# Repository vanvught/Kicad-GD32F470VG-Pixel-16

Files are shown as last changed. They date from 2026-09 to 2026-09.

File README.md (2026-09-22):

# Kicad GD32F470VG Pixel 16-ports x 4 Universes

Firmware [https://github.com/vanvught/GD32F470VG-Pixel-16-Ports](https://github.com/vanvught/GD32F470VG-Pixel-16-Ports)

More information [https://www.gd32-dmx.org/pixel.html](https://www.gd32-dmx.org/pixel.html)

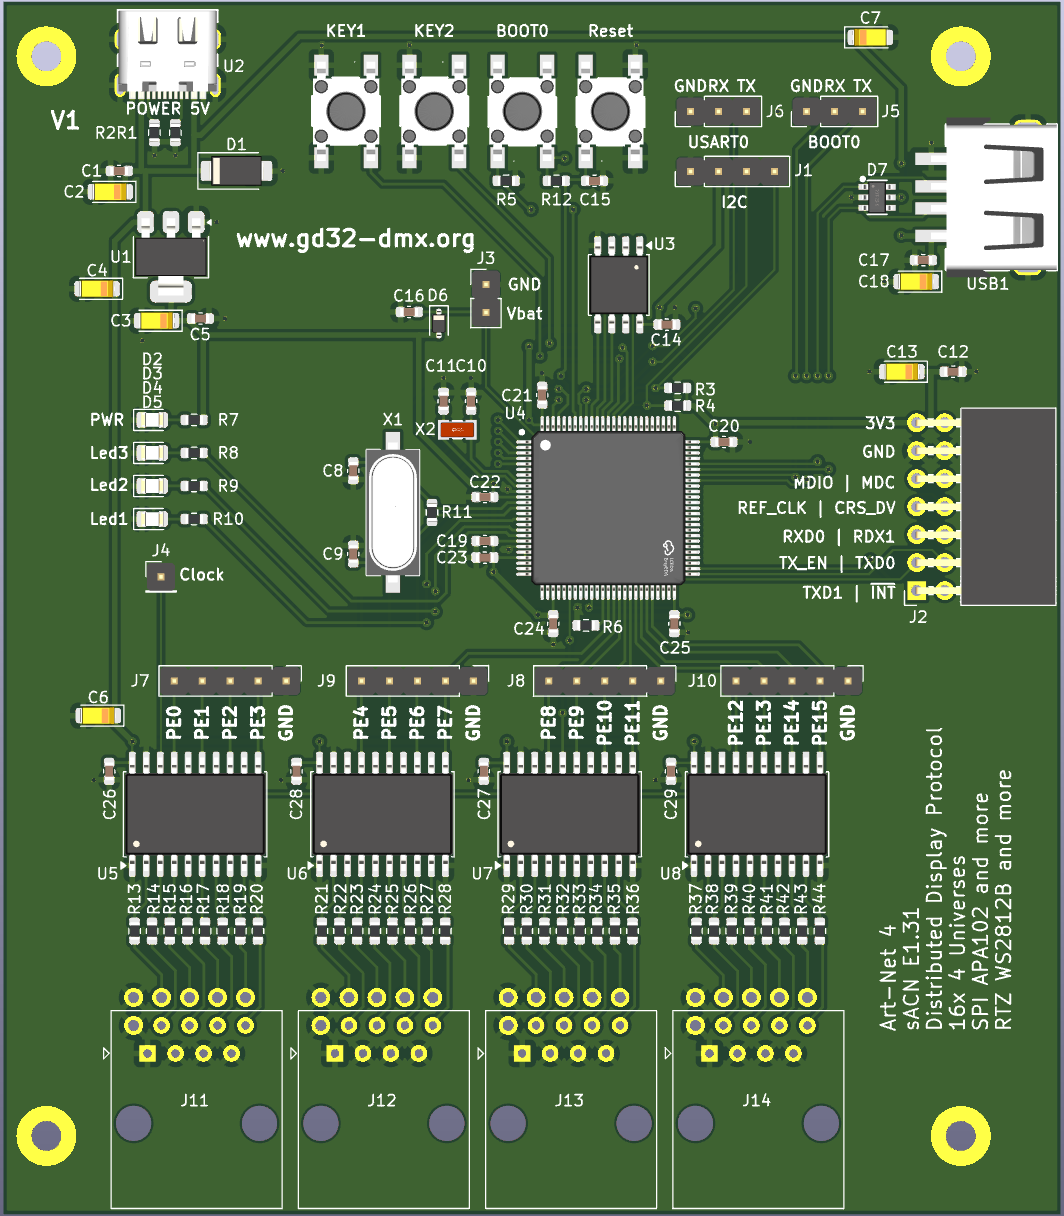
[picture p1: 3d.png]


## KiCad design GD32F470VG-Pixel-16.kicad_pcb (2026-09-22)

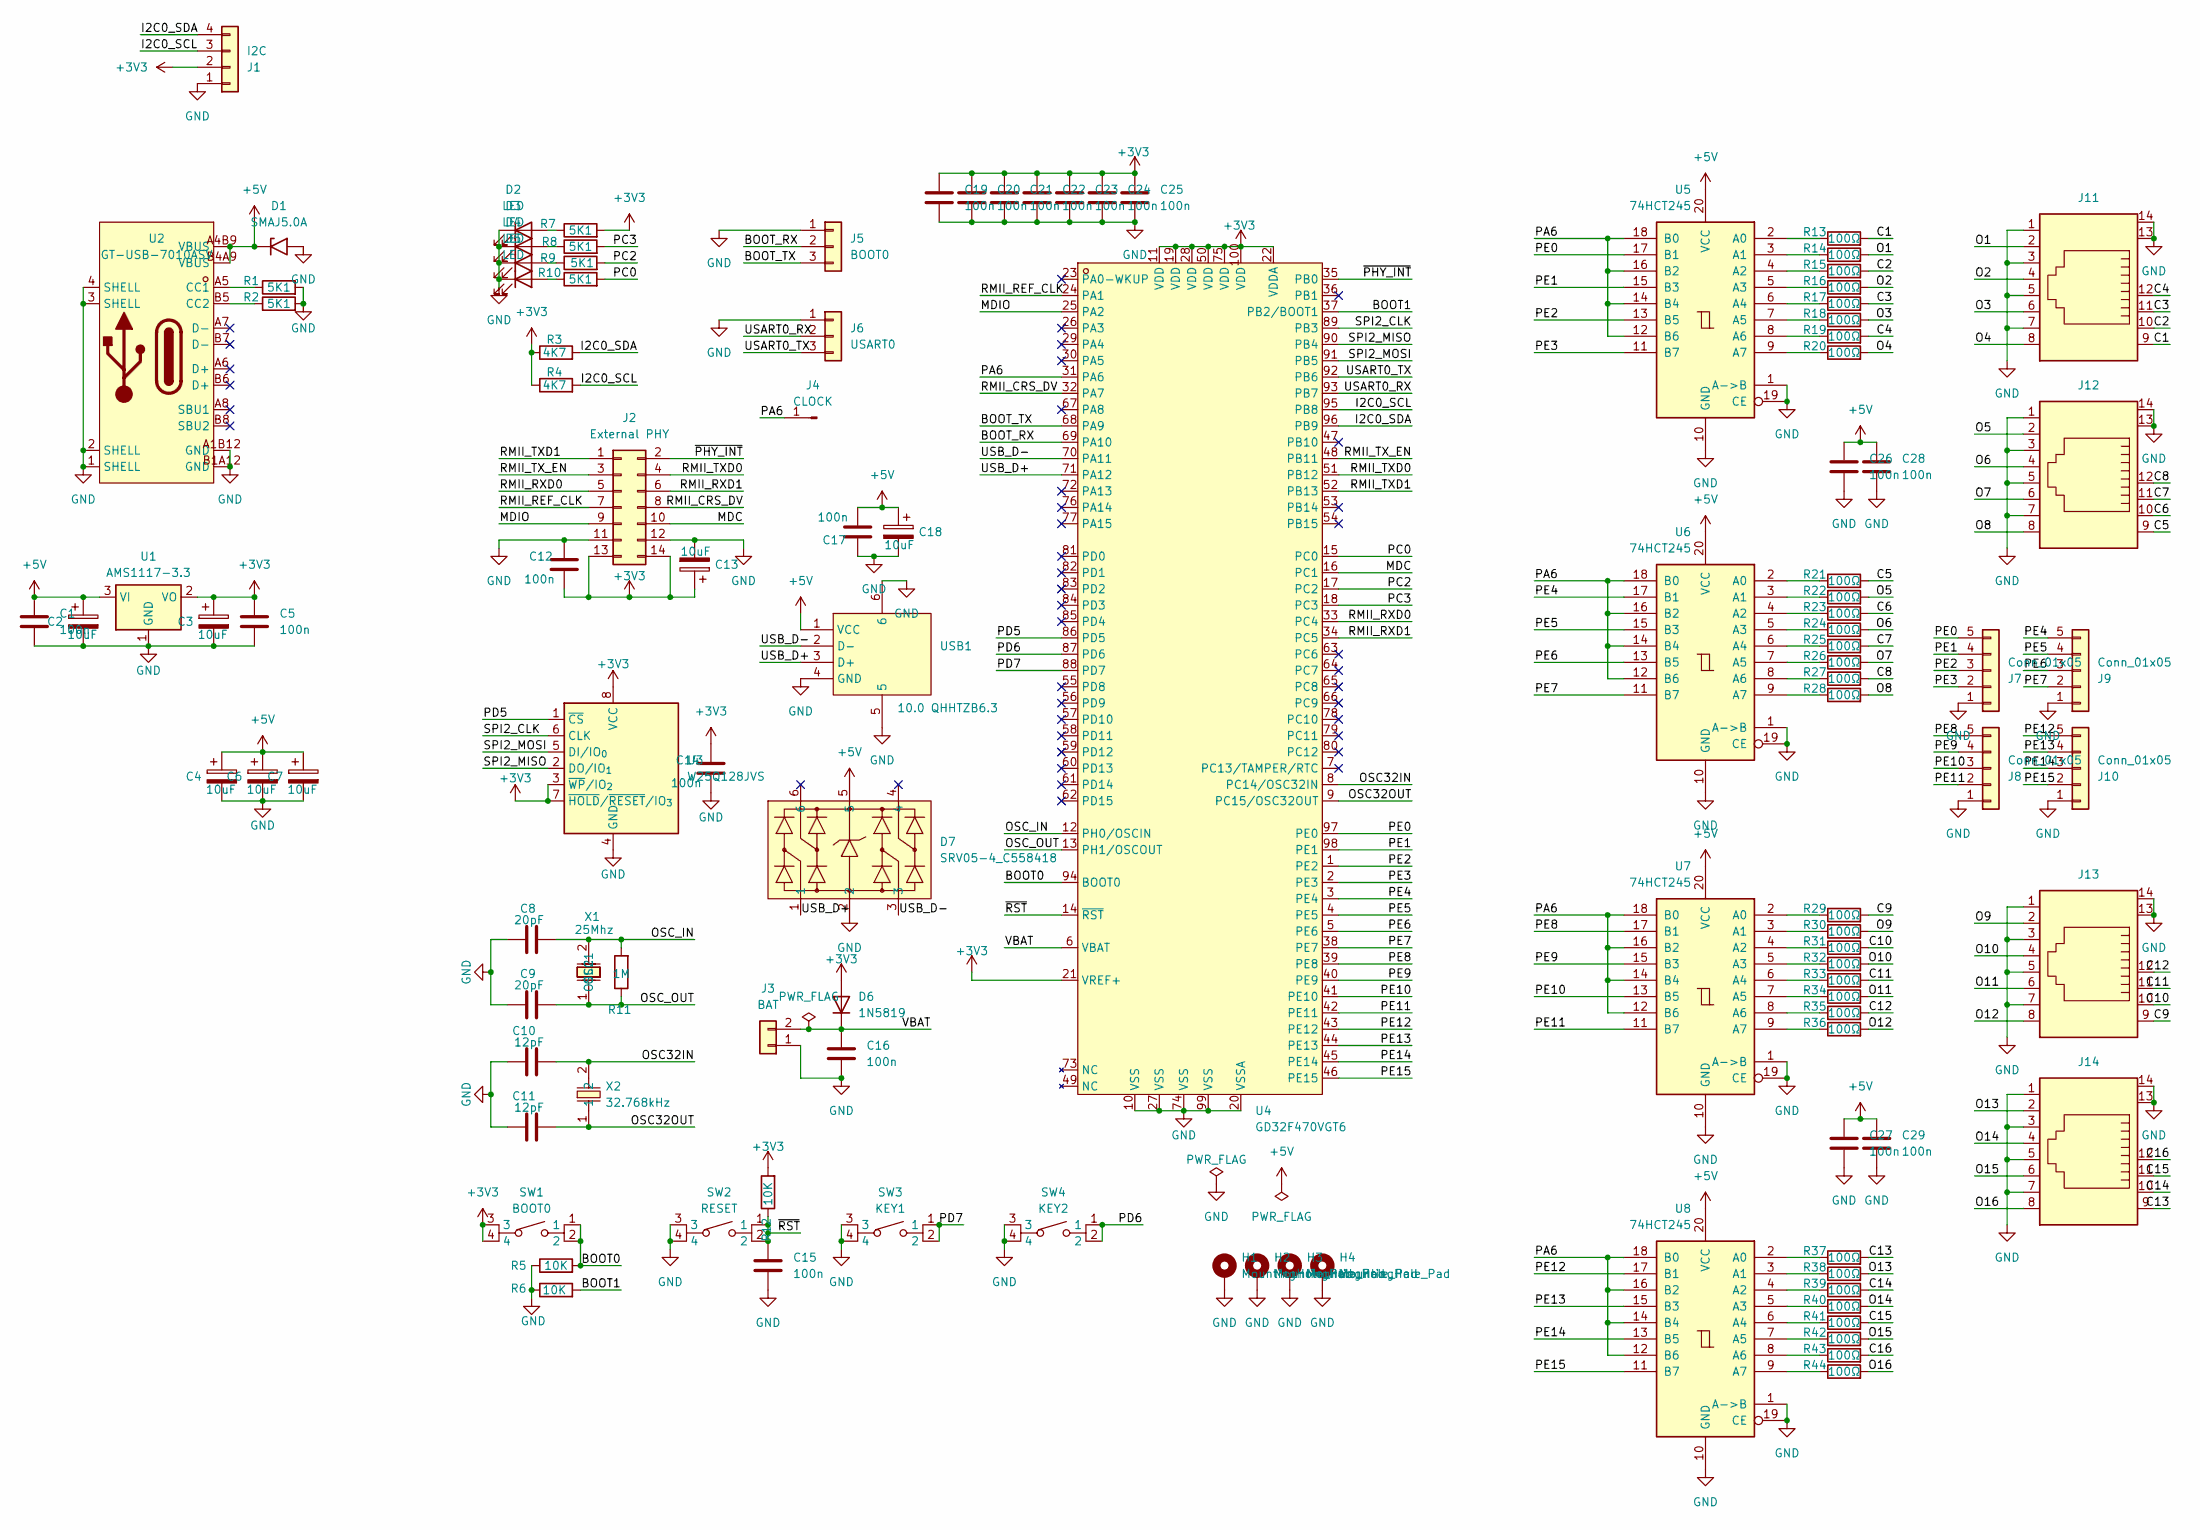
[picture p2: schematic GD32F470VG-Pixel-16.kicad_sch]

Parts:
C1, C5, C12, C14, C15, C16, C17, C19, C20, C21, C22, C23, C24, C25, C26, C27, C28, C29: 100n; C_0603_1608Metric; LCSC Part C14663
C2, C3, C4, C6, C7, C13, C18: 10uF; CP_EIA-3216-18_Kemet-A; LCSC Part C7171
C8, C9: 20pF; C_0603_1608Metric; LCSC Part C1648
C10, C11: 12pF; C_0603_1608Metric; LCSC Part C38523
D1: SMAJ5.0A; D_SMA; LCSC Part C113952
D2, D3, D4, D5: LED; LED_0805_2012Metric; LCSC Part C2297
D6: 1N5819; D_SOD-323; LCSC Part C48997863
D7: SRV05-4_C558418; SOT-23-6_L2.9-W1.6-P0.95-LS2.8-BL; MPN SRV05-4; LCSC Part C558418
H1, H2, H3, H4: MountingHole_Pad; MountingHole_2.7mm_M2.5_Pad
J1: I2C; PinHeader_1x04_P2.54mm_Vertical
J2: External PHY; PinSocket_2x07_P2.54mm_Horizontal
J3: BAT; PinHeader_1x02_P2.54mm_Vertical
J4: CLOCK; PinHeader_1x01_P2.54mm_Vertical
J5: BOOT0; PinHeader_1x03_P2.54mm_Vertical
J6: USART0; PinHeader_1x03_P2.54mm_Vertical
J7, J8, J9, J10: Conn_01x05; PinHeader_1x05_P2.54mm_Vertical
J11, J12, J13, J14: RJ45-with-additional-row
R1, R2, R7, R8, R9, R10: 5K1; R_0603_1608Metric; LCSC Part C23186
R3, R4: 4K7; R_0603_1608Metric; LCSC Part C23162
R5, R6, R12: 10K; R_0603_1608Metric; LCSC Part C25804
R11: 1M; R_0603_1608Metric; LCSC Part C22935
R13, R14, R15, R16, R17, R18, R19, R20, R21, R22, R23, R24, R25, R26, R27, R28, R29, R30, R31, R32, R33, R34, R35, R36, R37, R38, R39, R40, R41, R42, R43, R44: 100Ω; R_0603_1608Metric; LCSC Part C22775
SW1: BOOT0; KEY-SMD_4P-L6.0-W6.0-P4.50-LS9.0; MPN PTS645SM43SMTR92LFS; LCSC Part C221880
SW2: RESET; KEY-SMD_4P-L6.0-W6.0-P4.50-LS9.0; MPN PTS645SM43SMTR92LFS; LCSC Part C221880
SW3: KEY1; KEY-SMD_4P-L6.0-W6.0-P4.50-LS9.0; MPN PTS645SM43SMTR92LFS; LCSC Part C221880
SW4: KEY2; KEY-SMD_4P-L6.0-W6.0-P4.50-LS9.0; MPN PTS645SM43SMTR92LFS; LCSC Part C221880
U1: AMS1117-3.3; SOT-223-3_TabPin2
U2: GT-USB-7010ASV; USB-C-SMD_G-SWITCH_GT-USB-7010ASV; MPN GT-USB-7010ASV; LCSC Part C2988369
U3: W25Q128JVS; SOIC-8_5.3x5.3mm_P1.27mm; LCSC Part C97521
U4: GD32F470VGT6; LQFP-100_L14.0-W14.0-P0.50-LS16.0-BL; MPN GD32F470VGT6; LCSC Part C3029773
U5, U6, U7, U8: 74HCT245; SOIC-20W_7.5x12.8mm_P1.27mm; LCSC Part C5979
USB1: 10.0 QHHTZB6.3; USB-A-TH_10.0QHHTZB6.3; MPN 10.0 QHHTZB6.3; LCSC Part C668591
X1: 25Mhz; HC-49S_L11.4-W4.8; MPN X49SM25MSD2SC; LCSC Part C14872
X2: 32.768kHz; FC-135R_L3.2-W1.5; MPN Q13FC13500004; LCSC Part C32346

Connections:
+3V3: C3.1, C5.1, C12.2, C13.1, C14.1, C19.1, C20.1, C21.1, C22.1, C23.1, C24.1, C25.1, D6.2 (A), J1.2, J2.13, J2.14, R3.1, R4.1, R7.2, R12.2, SW1.3, SW1.4, U1.2 (VO), U3.3 (~WP/IO_{2}), U3.7 (~HOLD/~RESET/IO_{3}), U3.8 (VCC), U4.11 (VDD), U4.19 (VDD), U4.21 (VREF+), U4.22 (VDDA), U4.28 (VDD), U4.50 (VDD), U4.75 (VDD), U4.100 (VDD)
+5V: C1.1, C2.1, C4.1, C6.1, C7.1, C17.2, C18.1, C26.1, C27.1, C28.1, C29.1, D1.1 (A1), D7.5, U1.3 (VI), U2.A4B9 (VBUS), U2.B4A9 (VBUS), U5.20 (VCC), U6.20 (VCC), U7.20 (VCC), U8.20 (VCC), USB1.1 (VCC)
/BOOT0: R5.2, SW1.1, SW1.2, U4.94 (BOOT0)
/BOOT1: R6.2, U4.37 (PB2/BOOT1)
/BOOT_RX: J5.2, U4.69 (PA10)
/BOOT_TX: J5.3, U4.68 (PA9)
/C1: J11.9, R13.2
/C2: J11.10, R15.2
/C3: J11.11, R17.2
/C4: J11.12, R19.2
/C5: J12.9, R21.2
/C6: J12.10, R23.2
/C7: J12.11, R25.2
/C8: J12.12, R27.2
/C9: J13.9, R29.2
/C10: J13.10, R31.2
/C11: J13.11, R33.2
/C12: J13.12, R35.2
/C13: J14.9, R37.2
/C14: J14.10, R39.2
/C15: J14.11, R41.2
/C16: J14.12, R43.2
/I2C0_SCL: J1.3, R4.2, U4.95 (PB8)
/I2C0_SDA: J1.4, R3.2, U4.96 (PB9)
/MDC: J2.10, U4.16 (PC1)
/MDIO: J2.9, U4.25 (PA2)
/O1: J11.2, R14.2
/O2: J11.4, R16.2
/O3: J11.6, R18.2
/O4: J11.8, R20.2
/O5: J12.2, R22.2
/O6: J12.4, R24.2
/O7: J12.6, R26.2
/O8: J12.8, R28.2
/O9: J13.2, R30.2
/O10: J13.4, R32.2
/O11: J13.6, R34.2
/O12: J13.8, R36.2
/O13: J14.2, R38.2
/O14: J14.4, R40.2
/O15: J14.6, R42.2
/O16: J14.8, R44.2
/OSC32IN: C10.2, U4.8 (PC14/OSC32IN), X2.2
/OSC32OUT: C11.2, U4.9 (PC15/OSC32OUT), X2.1
/OSC_IN: C8.2, R11.2, U4.12 (PH0/OSCIN), X1.2 (OSC2)
/OSC_OUT: C9.2, R11.1, U4.13 (PH1/OSCOUT), X1.1 (OSC1)
/PA6: J4.1 (Pin_1_1), U4.31 (PA6), U5.12 (B6), U5.14 (B4), U5.16 (B2), U5.18 (B0), U6.12 (B6), U6.14 (B4), U6.16 (B2), U6.18 (B0), U7.12 (B6), U7.14 (B4), U7.16 (B2), U7.18 (B0), U8.12 (B6), U8.14 (B4), U8.16 (B2), U8.18 (B0)
/PC0: R10.2, U4.15 (PC0)
/PC2: R9.2, U4.17 (PC2)
/PC3: R8.2, U4.18 (PC3)
/PD5: U3.1 (~CS), U4.86 (PD5)
/PD6: SW4.1, SW4.2, U4.87 (PD6)
/PD7: SW3.1, SW3.2, U4.88 (PD7)
/PE0: J7.5, U4.97 (PE0), U5.17 (B1)
/PE1: J7.4, U4.98 (PE1), U5.15 (B3)
/PE2: J7.3, U4.1 (PE2), U5.13 (B5)
/PE3: J7.2, U4.2 (PE3), U5.11 (B7)
/PE4: J9.5, U4.3 (PE4), U6.17 (B1)
/PE5: J9.4, U4.4 (PE5), U6.15 (B3)
/PE6: J9.3, U4.5 (PE6), U6.13 (B5)
/PE7: J9.2, U4.38 (PE7), U6.11 (B7)
/PE8: J8.5, U4.39 (PE8), U7.17 (B1)
/PE9: J8.4, U4.40 (PE9), U7.15 (B3)
/PE10: J8.3, U4.41 (PE10), U7.13 (B5)
/PE11: J8.2, U4.42 (PE11), U7.11 (B7)
/PE12: J10.5, U4.43 (PE12), U8.17 (B1)
/PE13: J10.4, U4.44 (PE13), U8.15 (B3)
/PE14: J10.3, U4.45 (PE14), U8.13 (B5)
/PE15: J10.2, U4.46 (PE15), U8.11 (B7)
/RMII_CRS_DV: J2.8, U4.32 (PA7)
/RMII_REF_CLK: J2.7, U4.24 (PA1)
/RMII_RXD0: J2.5, U4.33 (PC4)
/RMII_RXD1: J2.6, U4.34 (PC5)
/RMII_TXD0: J2.4, U4.51 (PB12)
/RMII_TXD1: J2.1, U4.52 (PB13)
/RMII_TX_EN: J2.3, U4.48 (PB11)
/SPI2_CLK: U3.6 (CLK), U4.89 (PB3)
/SPI2_MISO: U3.2 (DO/IO_{1}), U4.90 (PB4)
/SPI2_MOSI: U3.5 (DI/IO_{0}), U4.91 (PB5)
/USART0_RX: J6.2, U4.93 (PB7)
/USART0_TX: J6.3, U4.92 (PB6)
/USB_D+: D7.1, U4.71 (PA12), USB1.3 (D+)
/USB_D-: D7.3, U4.70 (PA11), USB1.2 (D-)
/VBAT: C16.1, D6.1 (K), J3.2, U4.6 (VBAT)
/~PHY_INT: J2.2, U4.35 (PB0)
/~RST: C15.1, R12.1, SW2.1, SW2.2, U4.14 (~RST)
GND: C1.2, C2.2, C3.2, C4.2, C5.2, C6.2, C7.2, C8.1, C9.1, C10.1, C11.1, C12.1, C13.2, C14.2, C15.2, C16.2, C17.1, C18.2, C19.2, C20.2, C21.2, C22.2, C23.2, C24.2, C25.2, C26.2, C27.2, C28.2, C29.2, D1.2 (A2), D2.1 (K), D3.1 (K), D4.1 (K), D5.1 (K), D7.2, H1.1 (1_1), H2.1 (1_1), H3.1 (1_1), H4.1 (1_1), J1.1, J2.11, J2.12, J3.1, J5.1, J6.1, J7.1, J8.1, J9.1, J10.1, J11.1, J11.3, J11.5, J11.7, J11.13, J11.14, J12.1, J12.3, J12.5, J12.7, J12.13, J12.14, J13.1, J13.3, J13.5, J13.7, J13.13, J13.14, J14.1, J14.3, J14.5, J14.7, J14.13, J14.14, R1.2, R2.2, R5.1, R6.1, SW2.3, SW2.4, SW3.3, SW3.4, SW4.3, SW4.4, U1.1 (GND), U2.1 (SHELL), U2.2 (SHELL), U2.3 (SHELL), U2.4 (SHELL), U2.A1B12 (GND), U2.B1A12 (GND), U3.4 (GND), U4.10 (VSS), U4.20 (VSSA), U4.27 (VSS), U4.74 (VSS), U4.99 (VSS), U5.1 (A->B), U5.10 (GND), U5.19 (CE), U6.1 (A->B), U6.10 (GND), U6.19 (CE), U7.1 (A->B), U7.10 (GND), U7.19 (CE), U8.1 (A->B), U8.10 (GND), U8.19 (CE), USB1.4 (GND), USB1.5, USB1.6
unnamed: D2.2 (A), R7.1
unnamed: D3.2 (A), R8.1
unnamed: D4.2 (A), R9.1
unnamed: D5.2 (A), R10.1
unnamed: R1.1, U2.A5 (CC1)
unnamed: R2.1, U2.B5 (CC2)
unnamed: R13.1, U5.2 (A0)
unnamed: R14.1, U5.3 (A1)
unnamed: R15.1, U5.4 (A2)
unnamed: R16.1, U5.5 (A3)
unnamed: R17.1, U5.6 (A4)
unnamed: R18.1, U5.7 (A5)
unnamed: R19.1, U5.8 (A6)
unnamed: R20.1, U5.9 (A7)
unnamed: R21.1, U6.2 (A0)
unnamed: R22.1, U6.3 (A1)
unnamed: R23.1, U6.4 (A2)
unnamed: R24.1, U6.5 (A3)
unnamed: R25.1, U6.6 (A4)
unnamed: R26.1, U6.7 (A5)
unnamed: R27.1, U6.8 (A6)
unnamed: R28.1, U6.9 (A7)
unnamed: R29.1, U7.2 (A0)
unnamed: R30.1, U7.3 (A1)
unnamed: R31.1, U7.4 (A2)
unnamed: R32.1, U7.5 (A3)
unnamed: R33.1, U7.6 (A4)
unnamed: R34.1, U7.7 (A5)
unnamed: R35.1, U7.8 (A6)
unnamed: R36.1, U7.9 (A7)
unnamed: R37.1, U8.2 (A0)
unnamed: R38.1, U8.3 (A1)
unnamed: R39.1, U8.4 (A2)
unnamed: R40.1, U8.5 (A3)
unnamed: R41.1, U8.6 (A4)
unnamed: R42.1, U8.7 (A5)
unnamed: R43.1, U8.8 (A6)
unnamed: R44.1, U8.9 (A7)

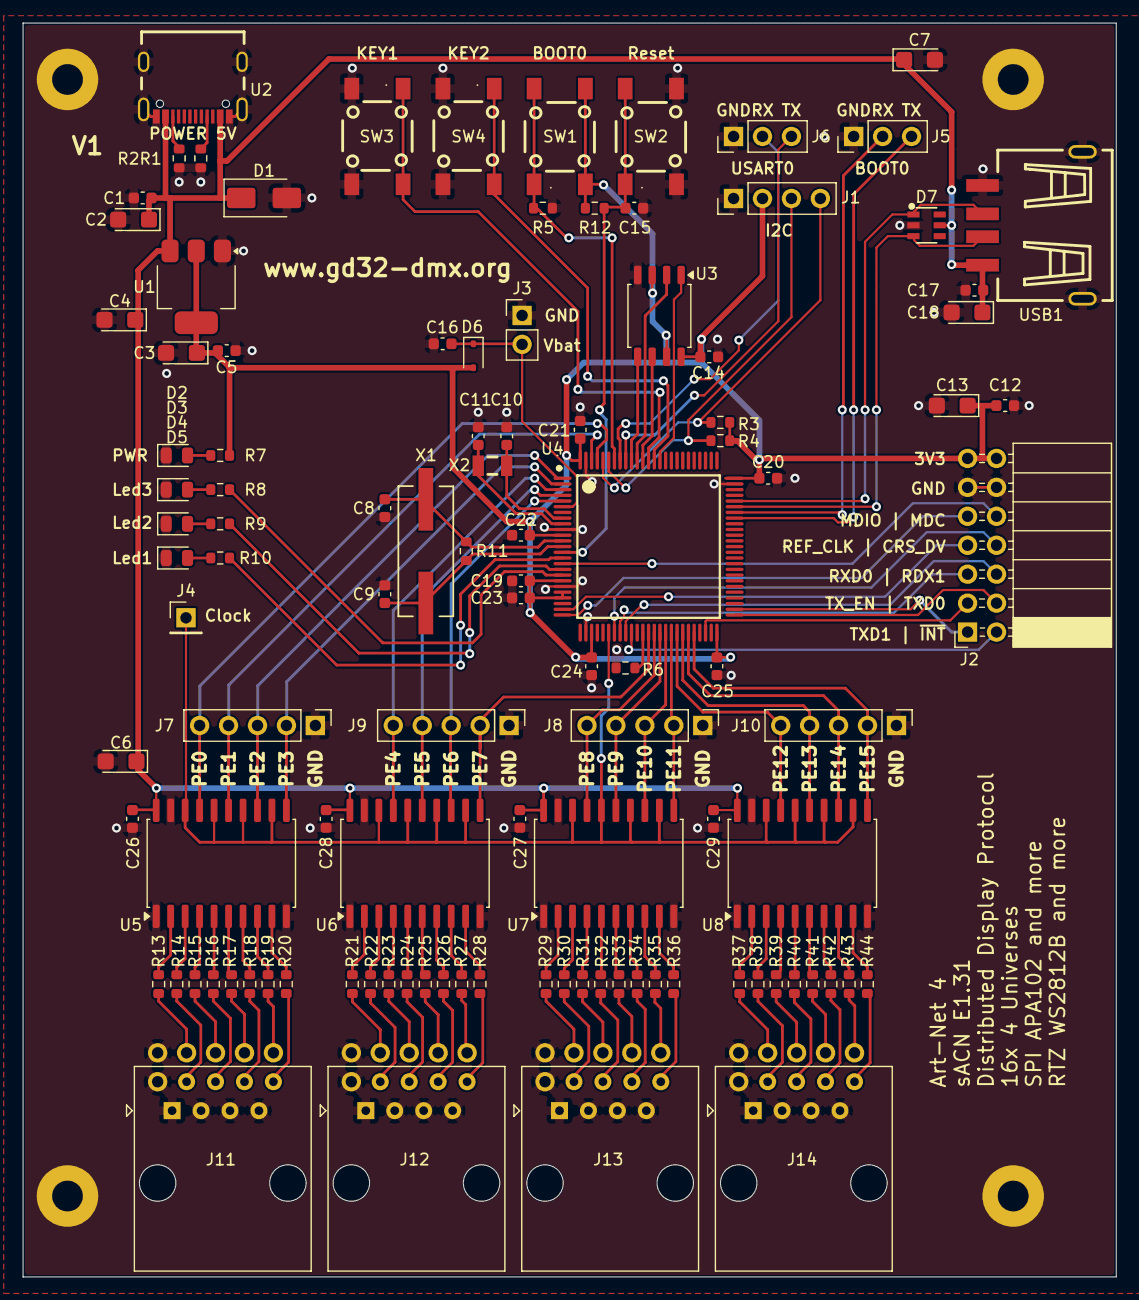
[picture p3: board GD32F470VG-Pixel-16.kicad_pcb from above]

Board: 2 copper layers, 96.0 x 110.0 mm, 113 parts (0 on the bottom side), 125 nets.
